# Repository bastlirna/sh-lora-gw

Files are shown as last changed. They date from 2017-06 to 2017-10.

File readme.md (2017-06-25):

# SH LoRa GW



In this repository there are materials created during making of LoRaWAN Gateway and its installation on Strahov dormitory. 

Mainly this is place where we store documentation for ourselves. But we hope that this could be inspiration for another GW builders.

## Table of content

* [Project organization](https://github.com/bastlirna/sh-lora-gw/projects/1)
* [Documentation](https://github.com/bastlirna/sh-lora-gw/wiki)

## Credits

Gateway is created in cooperation of [MacGyver hacker space](http://macgyver.sh.cvut.cz/), students club [Silicon Hill](http://www.siliconhill.cz/) and [CESNET association](https://www.cesnet.cz/?lang=en).

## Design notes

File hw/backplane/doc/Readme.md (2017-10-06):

# LoRaWAN Gateway - backplane

## Base components
 - Raspberry Pi 3 Model B (small single-board ARMv8 computer)
 - iC880A (RF frontend for LoRa technology)
 - STM32F103 (CortexM3 MCU)
 - u-blox NEO 6 (GPS frontend with PPS output)

## Function(s)
 1. LoRaWAN concetrator with packet time-mark support.
    - TheThingNetwork community gateway
    - Own implementation or alternative opensource backends
 2. NTP stratum 0
    - PPS signal from GPS can be used as reference signal for NTP server
 3. DGPS base station
    - RAW data can be used for precise navigation of many things (robots, cars, ...)
 4. Long time performance and stability testing for SDcard based computers
    - Primary purpose of STM32 MCU is watchdog and log records management for RPi
    - There is a 8Mbit FLASH for store stdout output on serial line
    - BMP280 can measure temperature and presure with great accuracy for long time

## Documentation
[PDF with schematic](LoRaGW-backplane.PDF)

### 3D model screenshot:
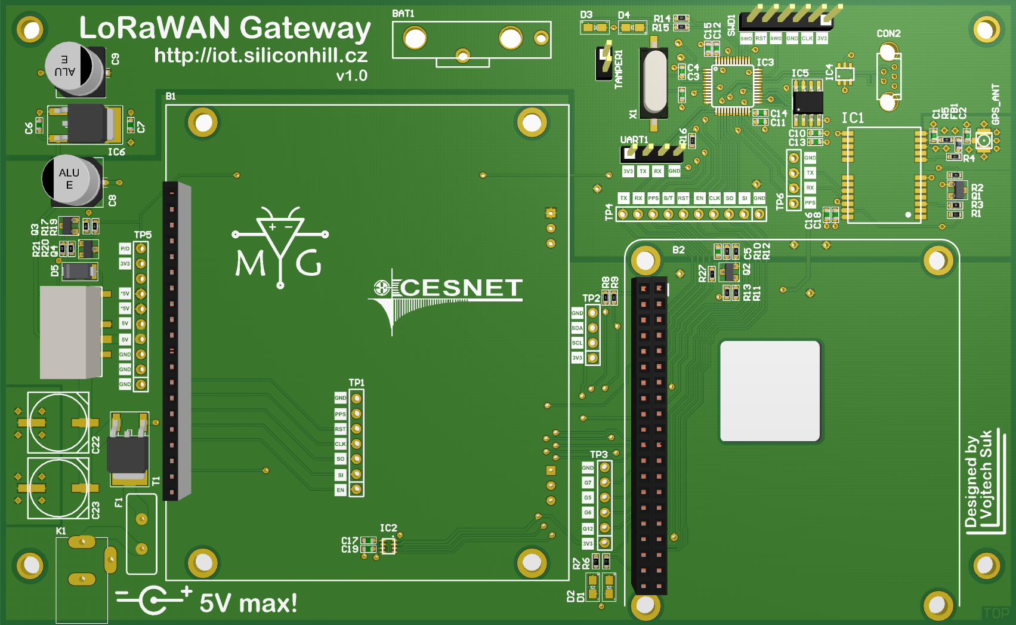
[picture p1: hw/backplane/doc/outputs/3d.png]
LoRaWAN backplane LoRaWAN backplane v1.0 3D


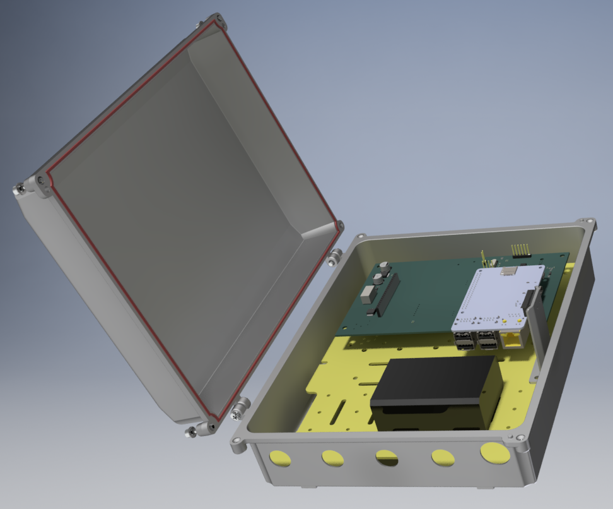
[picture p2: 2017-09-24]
hw/backplane/mechanical/box10.png

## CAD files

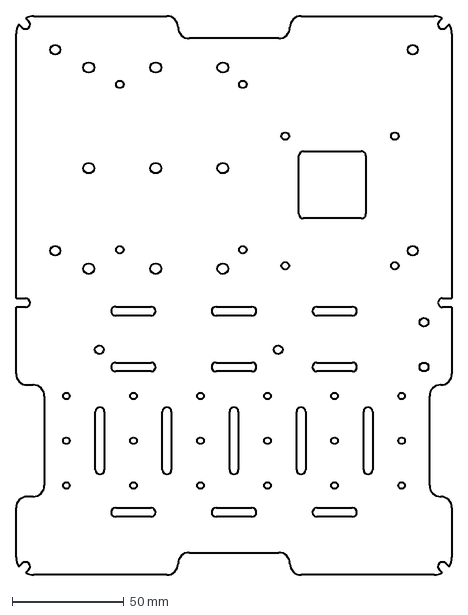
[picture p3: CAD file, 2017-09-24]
hw/backplane/mechanical/backplane.dxf
195.0 x 250.0 mm

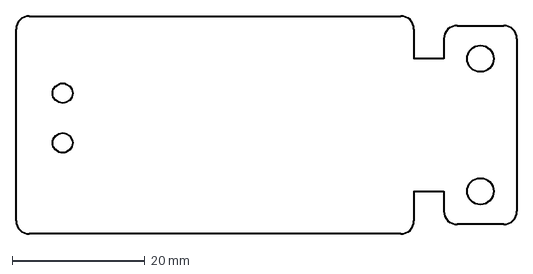
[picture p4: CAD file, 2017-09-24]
hw/backplane/mechanical/tactile_switch_holder.dxf
75.5 x 32.9 mm

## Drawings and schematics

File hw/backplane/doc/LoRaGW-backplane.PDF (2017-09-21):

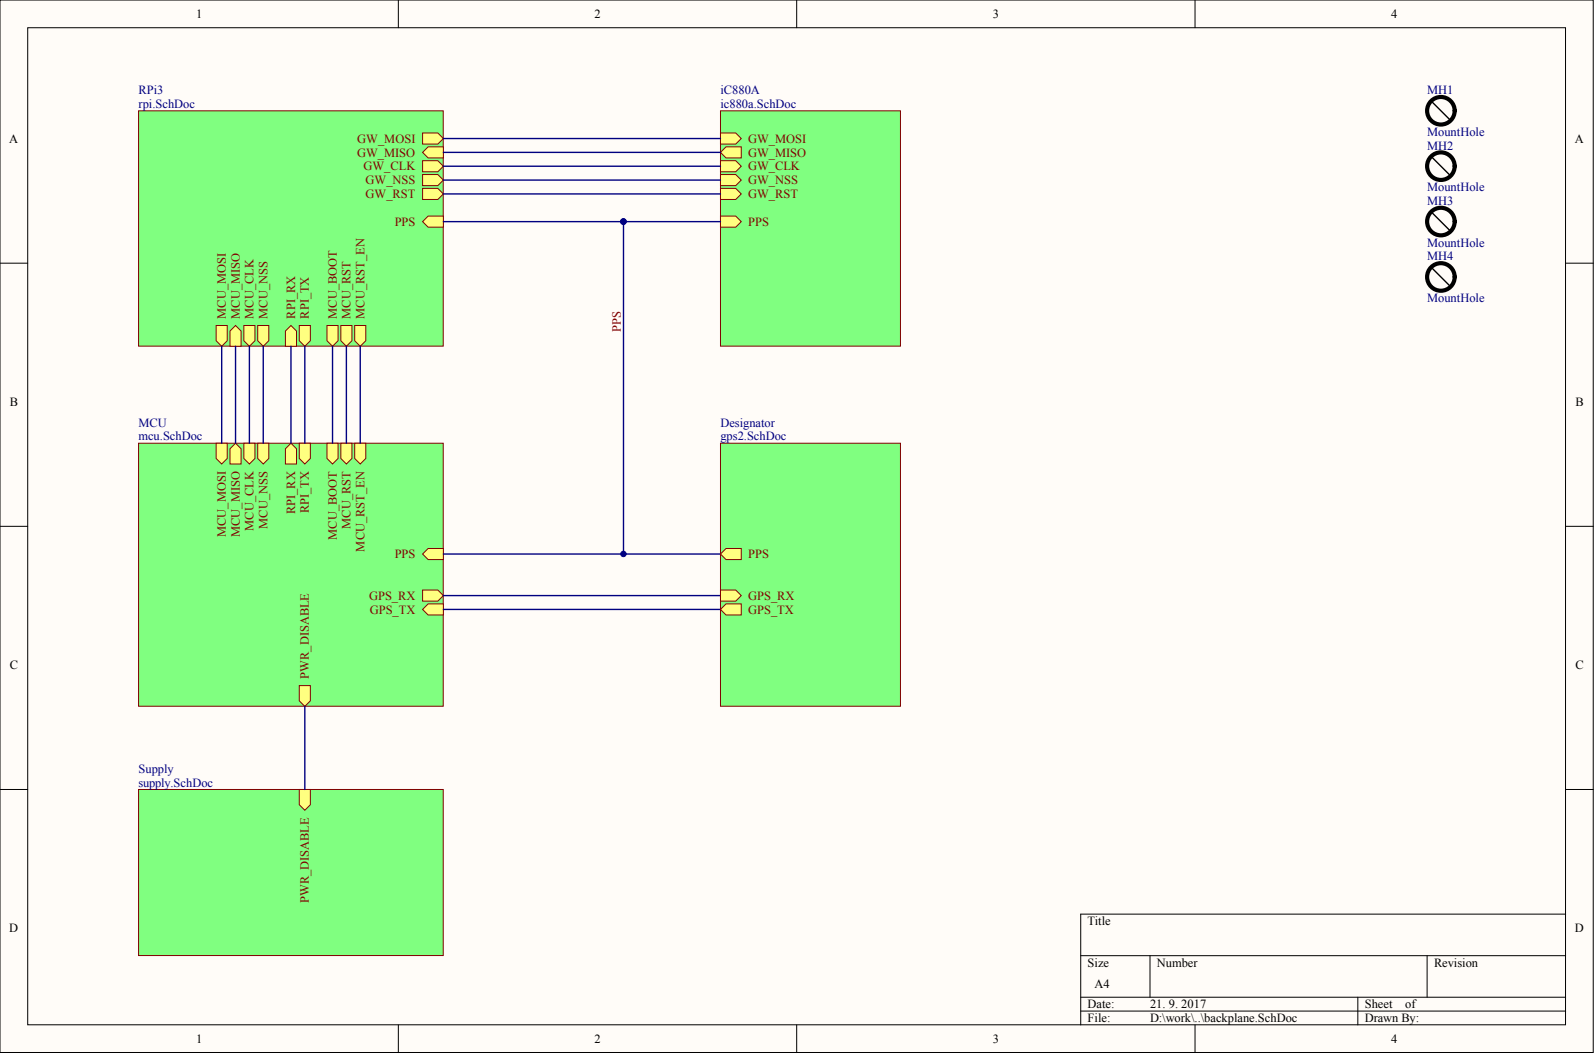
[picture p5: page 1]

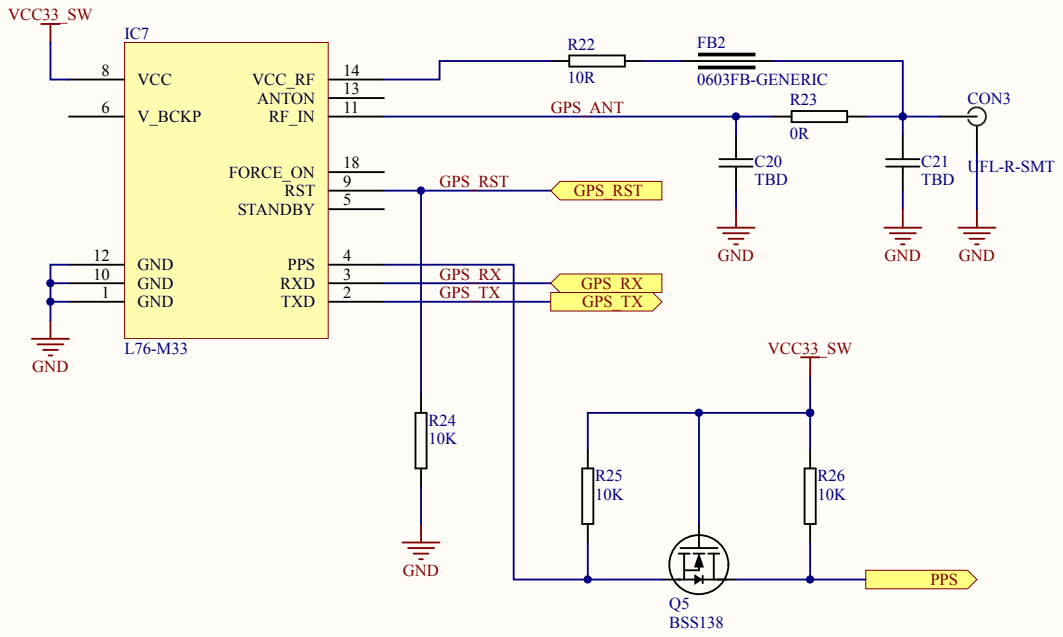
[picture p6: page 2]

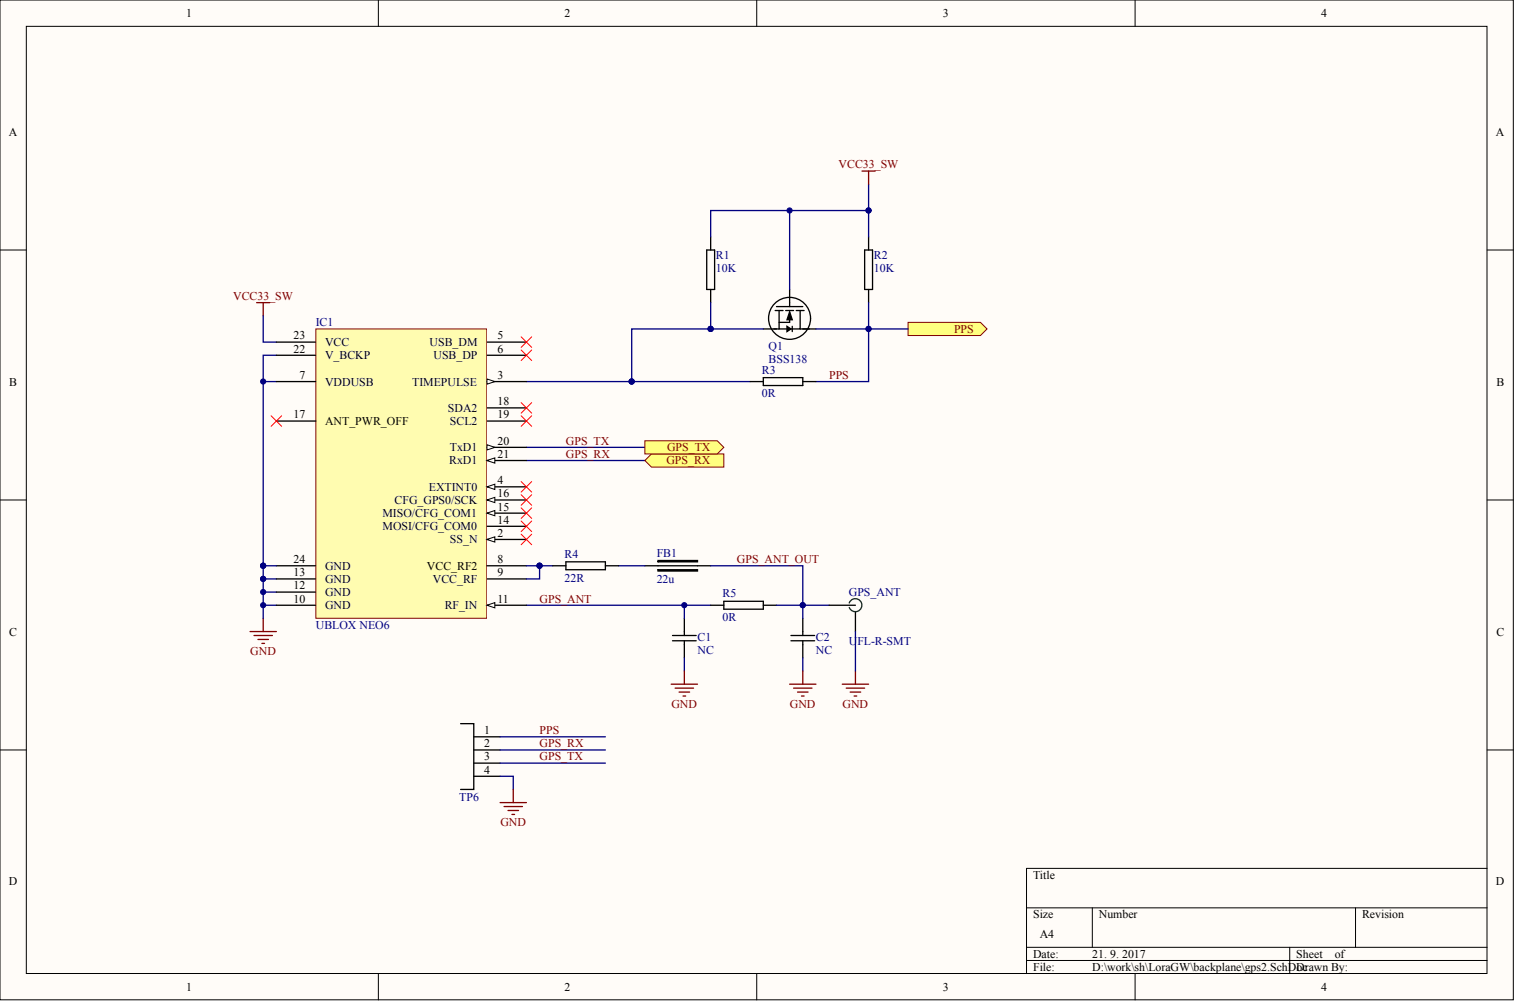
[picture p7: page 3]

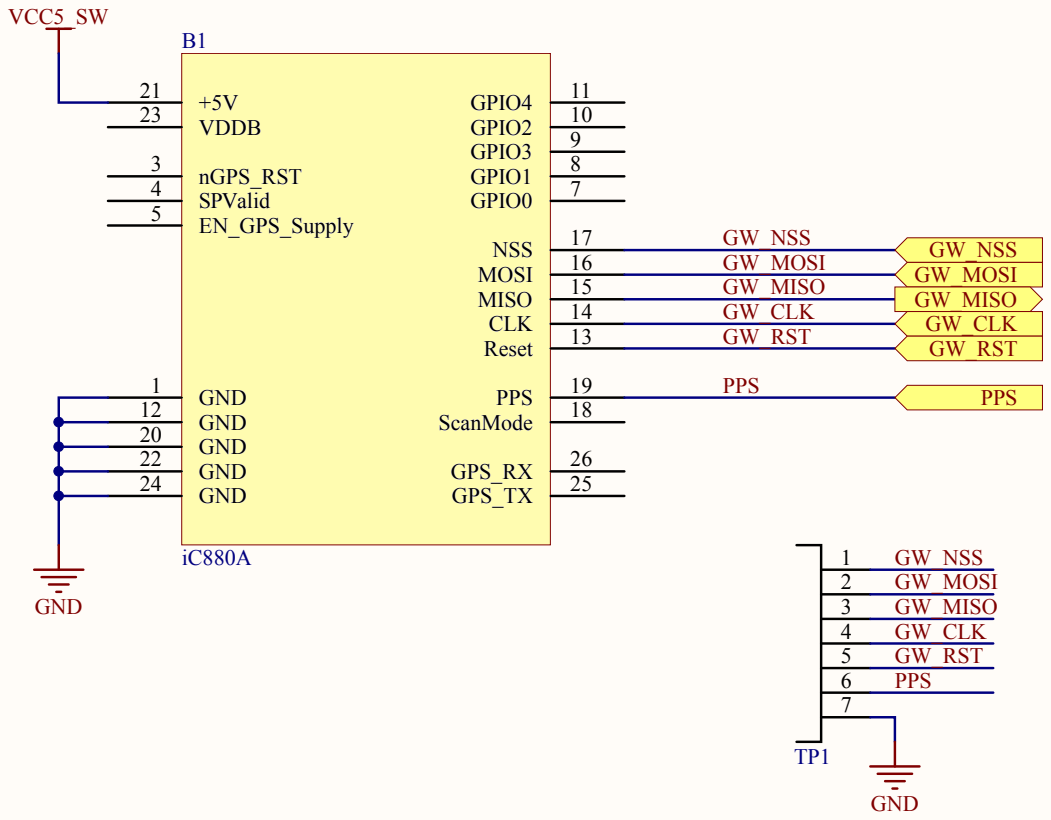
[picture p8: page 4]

GND 12

GND 22

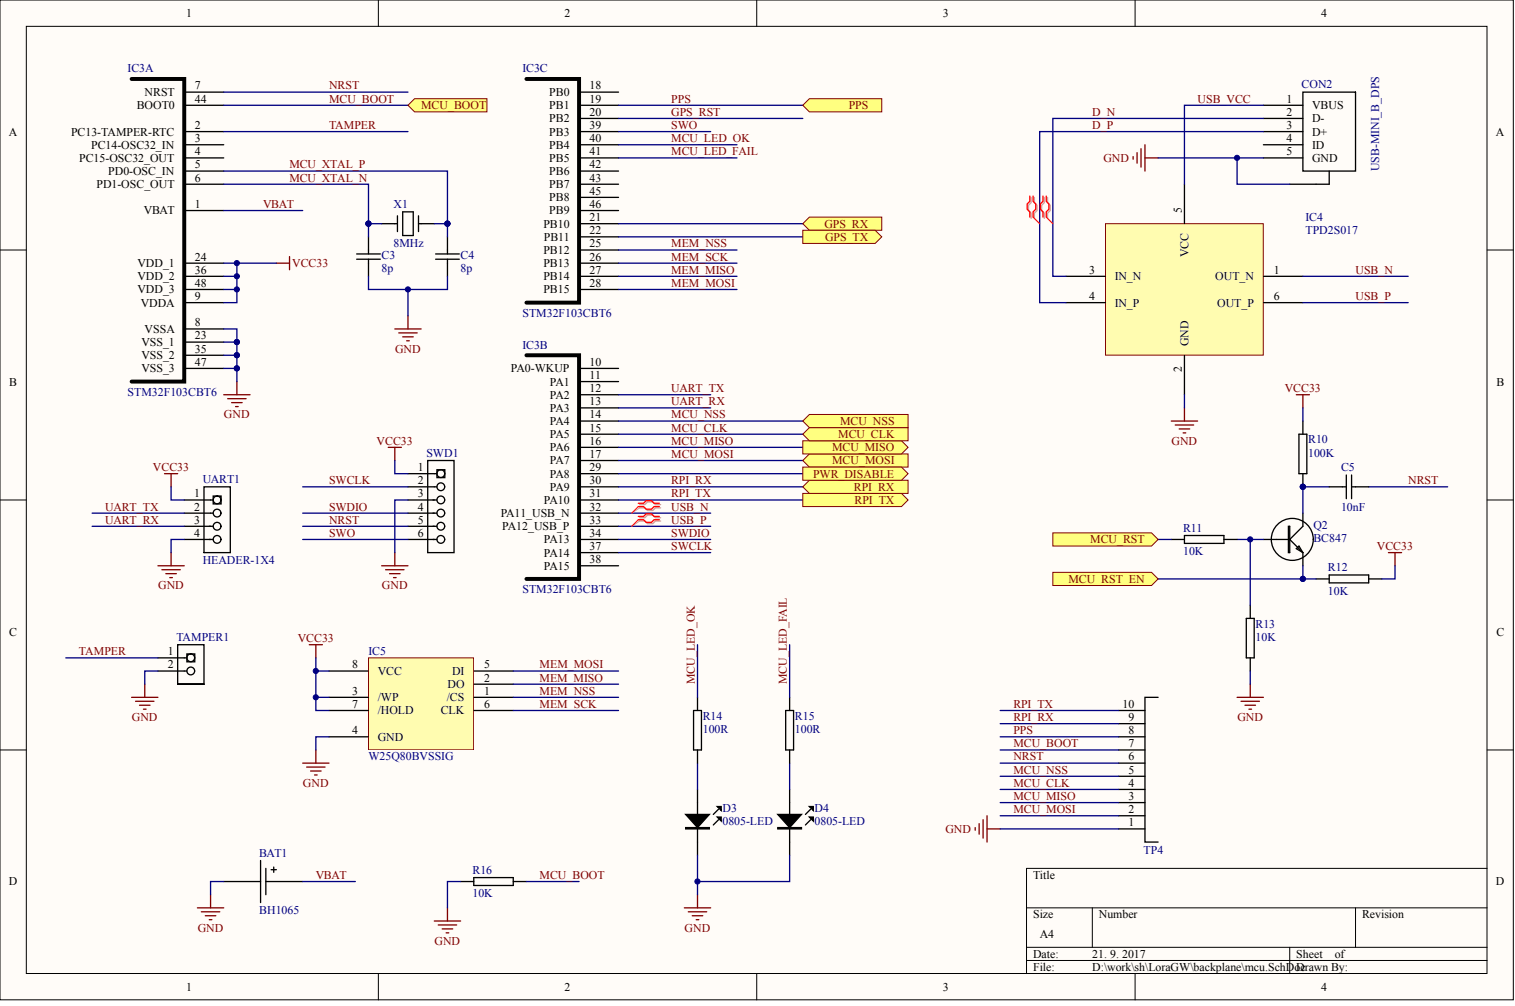
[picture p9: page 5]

GND 5

MCU_XTAL_N

VBAT

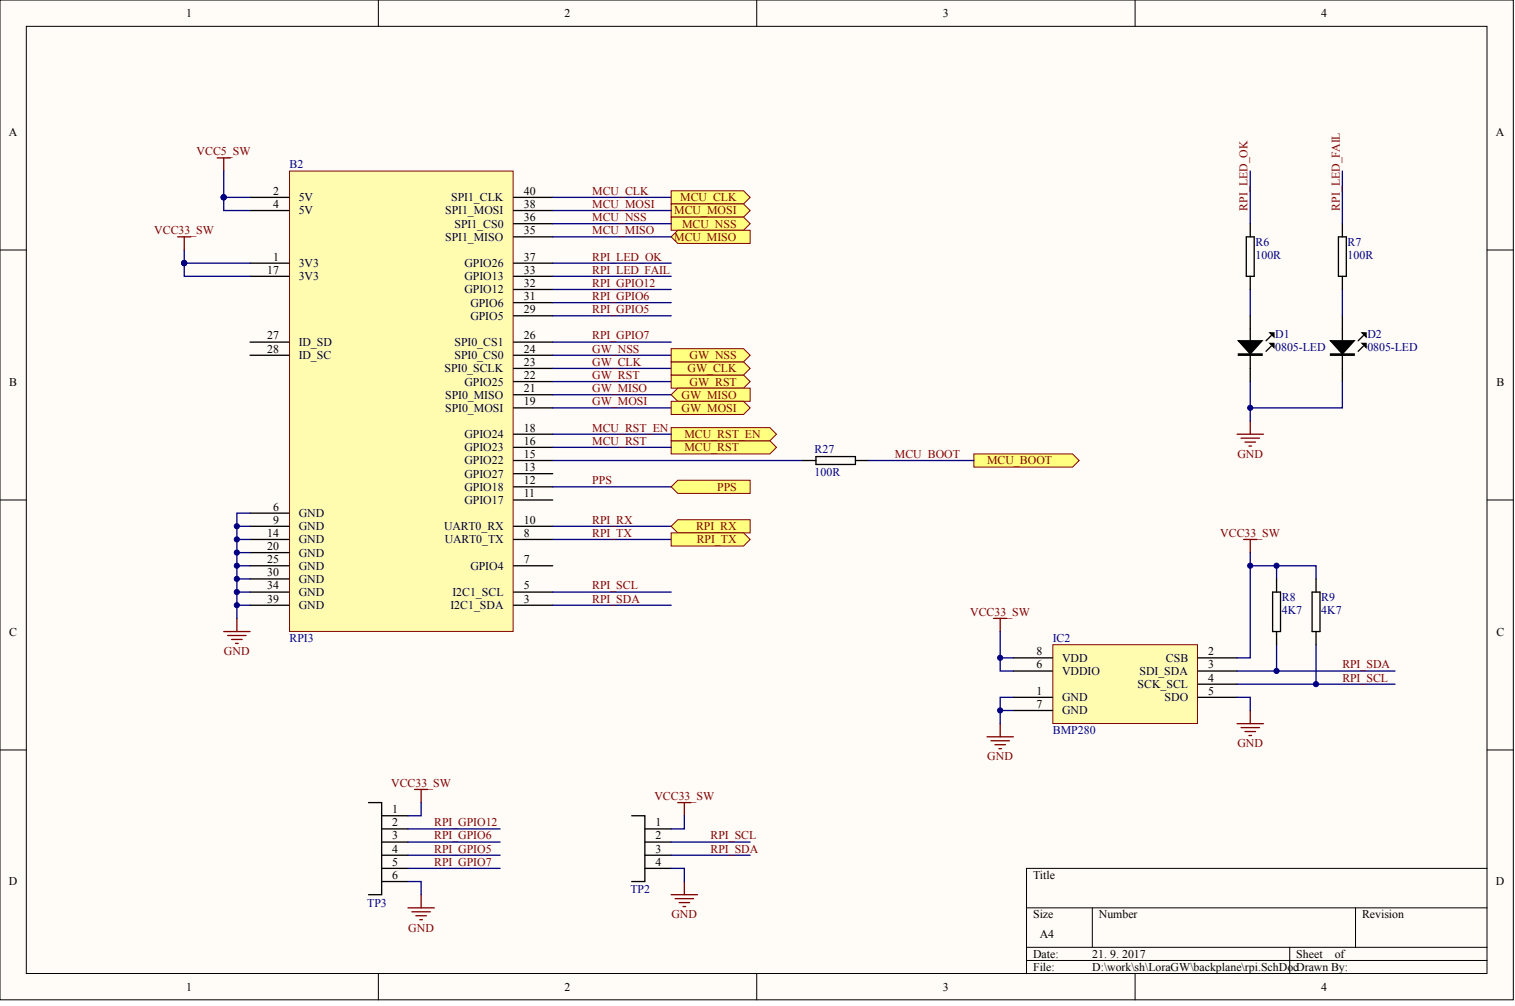
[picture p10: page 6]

GND 14
GND 20
GND 25
GND 30
GND 34
GND 39 | 3 RPI_SDA

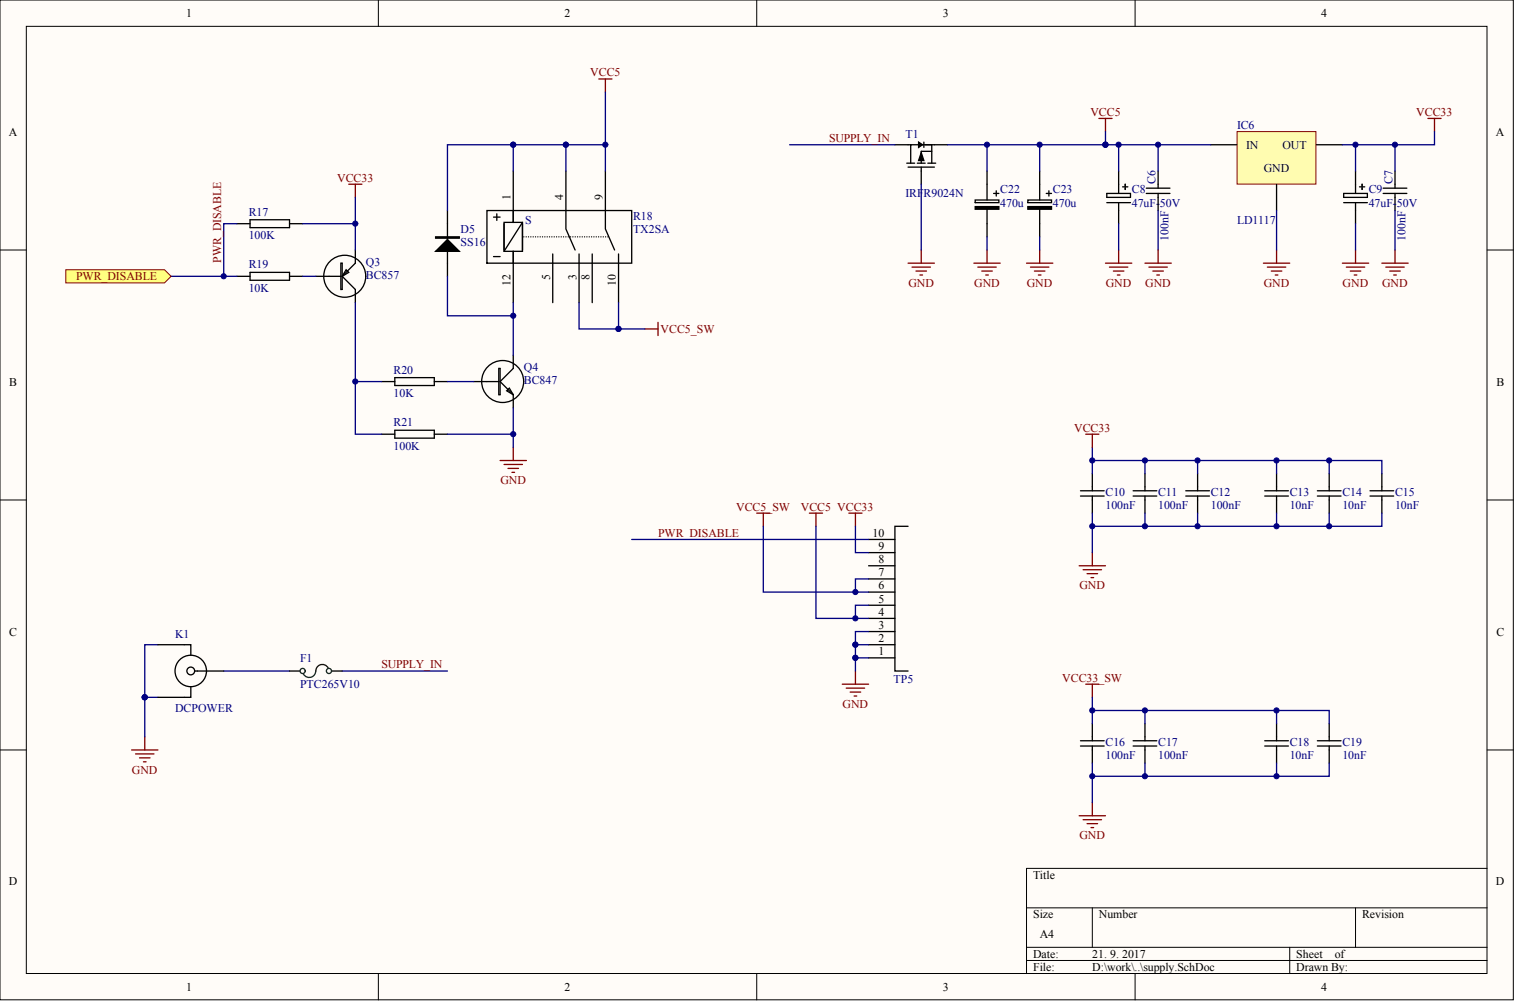
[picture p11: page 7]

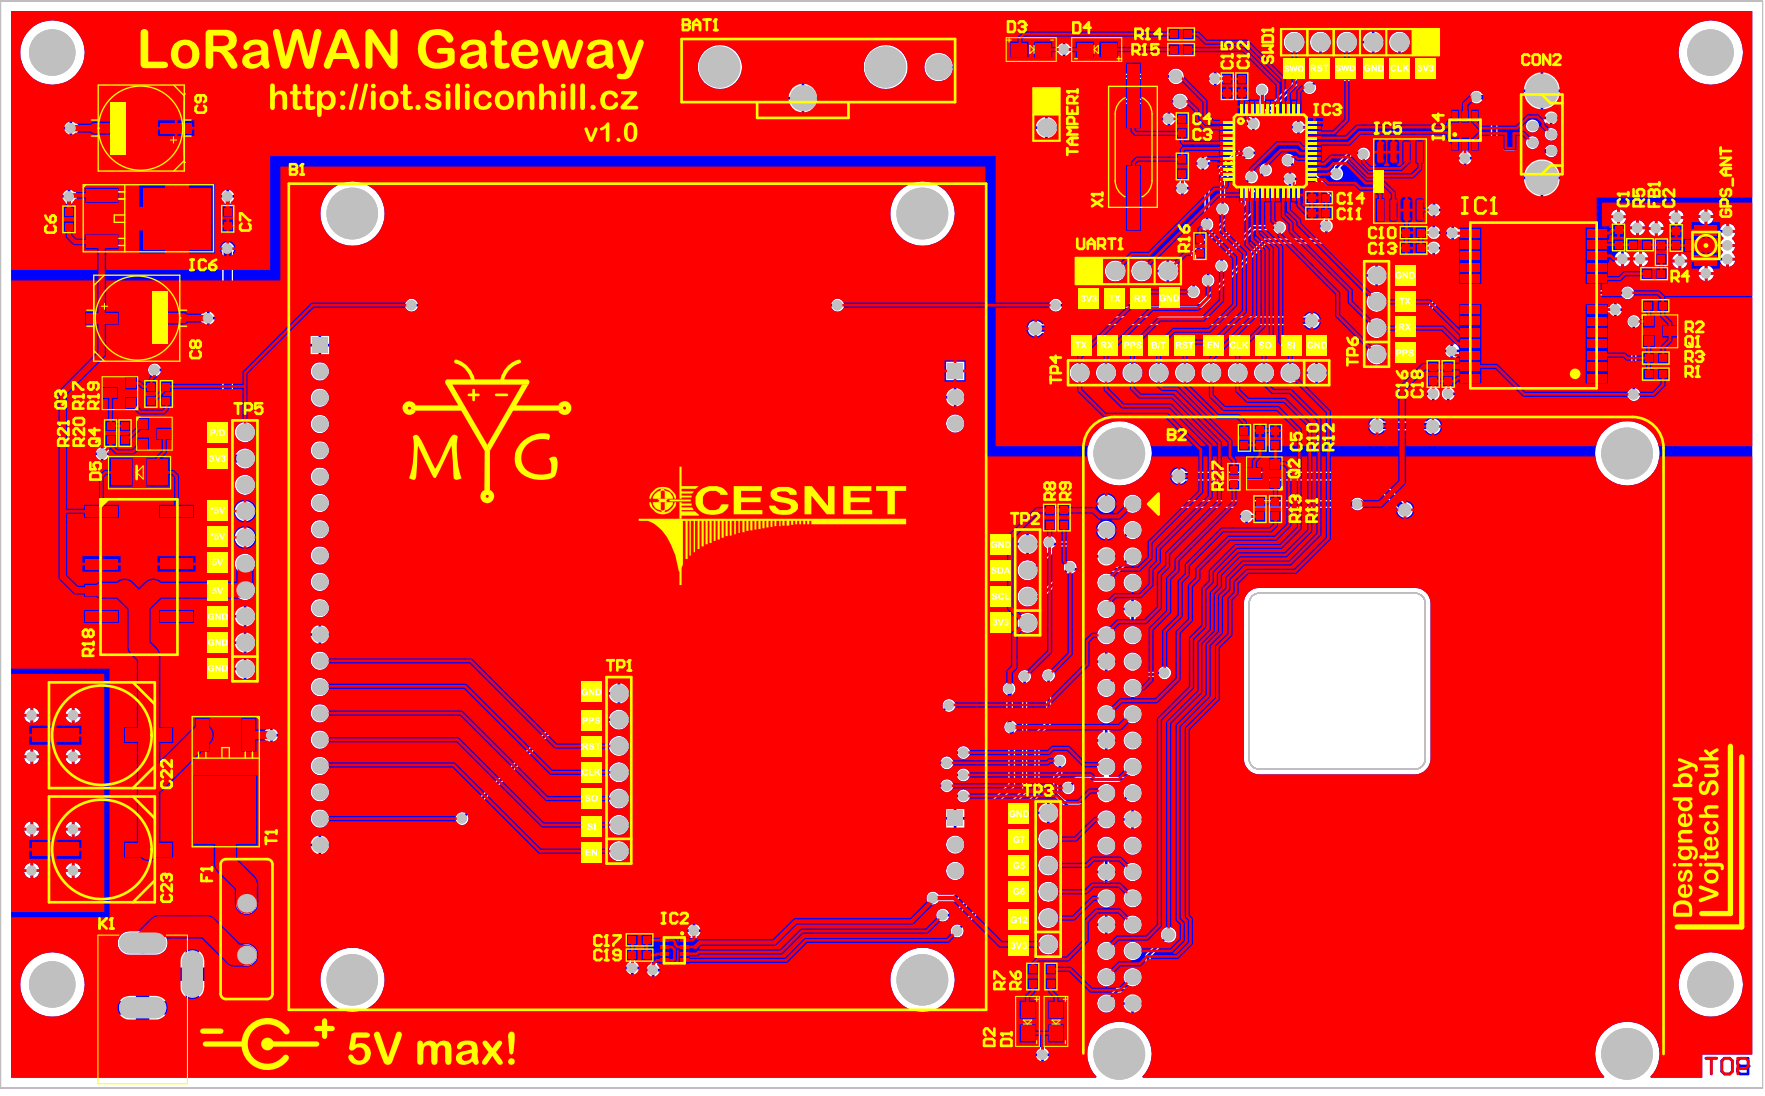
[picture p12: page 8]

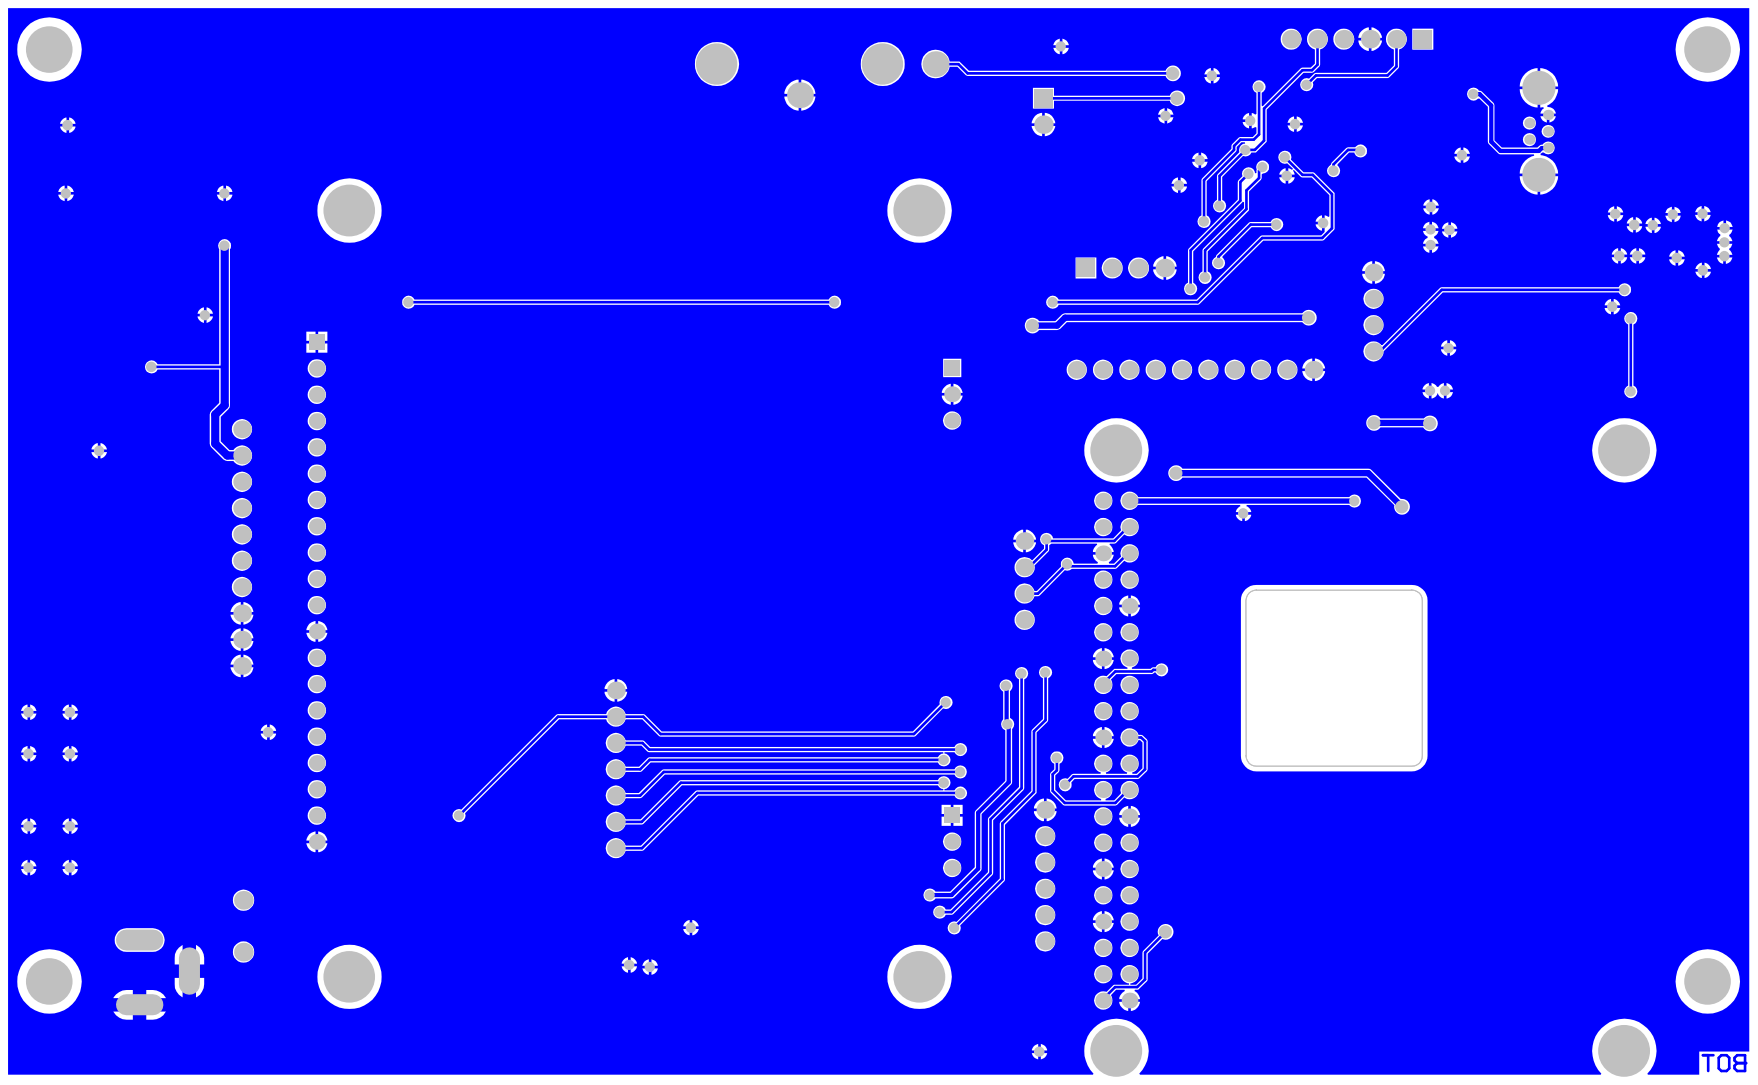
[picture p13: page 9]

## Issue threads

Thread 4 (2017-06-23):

GW SW installation

jhuspek, 2017-06-23:
Prepare SD card for RPi. Including documentation of installation process and scripts (there will be 2 of GWs - make it automatic as much as possible :wink:

jhuspek, 2017-06-23:
Example of installation: https://github.com/ttn-zh/ic880a-gateway

ah01, 2017-11-02:
Correct instruction for SPI concentrator: https://github.com/ttn-zh/ic880a-gateway/tree/spi

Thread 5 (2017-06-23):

Design PCB for GW

jhuspek, 2017-06-23:
Interface board between RPi, iC880A and other components including parts from Issue #2

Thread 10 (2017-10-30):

Wrong mount hole size on PCB

sukvojte, 2017-10-30:
There is a wrong mounting hole on corner of the backplane PCB. It may be a 4mm, not 3mm.

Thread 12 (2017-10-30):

Wrong component for fuse

sukvojte, 2017-10-30:
Backplabe board using a bad component as fuse (F1). PTC265V10 has a wrong current characteristic, so is useless.

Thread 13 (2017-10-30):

Wrong FLASH package type

sukvojte, 2017-10-30:
Used FLASH memory (W25Q80BV) have a two type of SOIC8 packages. On layout is used 150-mil version, but in BOM is 208-mil version. So is very hard to solder it.

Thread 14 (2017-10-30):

Wrong baterry holder layout

sukvojte, 2017-10-30:
Layout for battery holder has a bad distance between "big" drills.

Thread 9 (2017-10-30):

Missing pull-up resistor on USB

sukvojte, 2017-10-30:
There is missing 1.5k pull-up resistor on USB D+ line. It's required for identification USB device to host

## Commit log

2017-09-20 Added outputs for manufacture
    [backplane.GBL, backplane.GBO, backplane.GBS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]
2017-09-21 final version 1.0
    [backplane.GBL, backplane.GBO, backplane.GBS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]
2017-09-24 Added mechanical components
    [backplane.dxf, tactile_switch_holder.dxf]
